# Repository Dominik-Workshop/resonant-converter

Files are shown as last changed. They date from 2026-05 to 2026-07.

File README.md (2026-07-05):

# Resonant Converter

 

<p align="center">
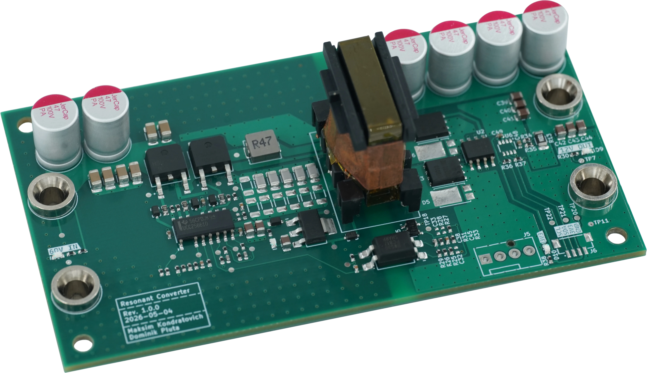
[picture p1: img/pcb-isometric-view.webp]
Hero image
  
</p>

## Overview

This project is an LLC resonant converter. The power supply is designed to step down a nominal 60V input to a 12V output, capable of delivering up to 10A of continuous current (120W).

The board features power telemetry using an INA219 sensor, which can be easily interfaced via a standard QWIIC connector.

### Key Features

* **Input Voltage:** 60V ± 5%
* **Output:** 12V @ 10A
* **Topology:** LLC Resonant Converter
* **Telemetry:** Onboard INA219 power monitor with a QWIIC I2C connector
* **Magnetics:** Custom-wound transformer

## Project Status

**Design:** ✅ → **Fabrication & Assembly:** ✅ → **Bring-up:** ✅

> [!IMPORTANT]
> **Hardware modification required (rev.1.0.0):**
>
> Replace `R20` with a diode (e.g. `1N4148`) to prevent VCCP from backfeeding `U3`. Without this fix, VCCP remains too low for the LLC controller `U1` to start up.

## Used Tools

* [KiCad](https://www.kicad.org/) - Schematic and PCB design

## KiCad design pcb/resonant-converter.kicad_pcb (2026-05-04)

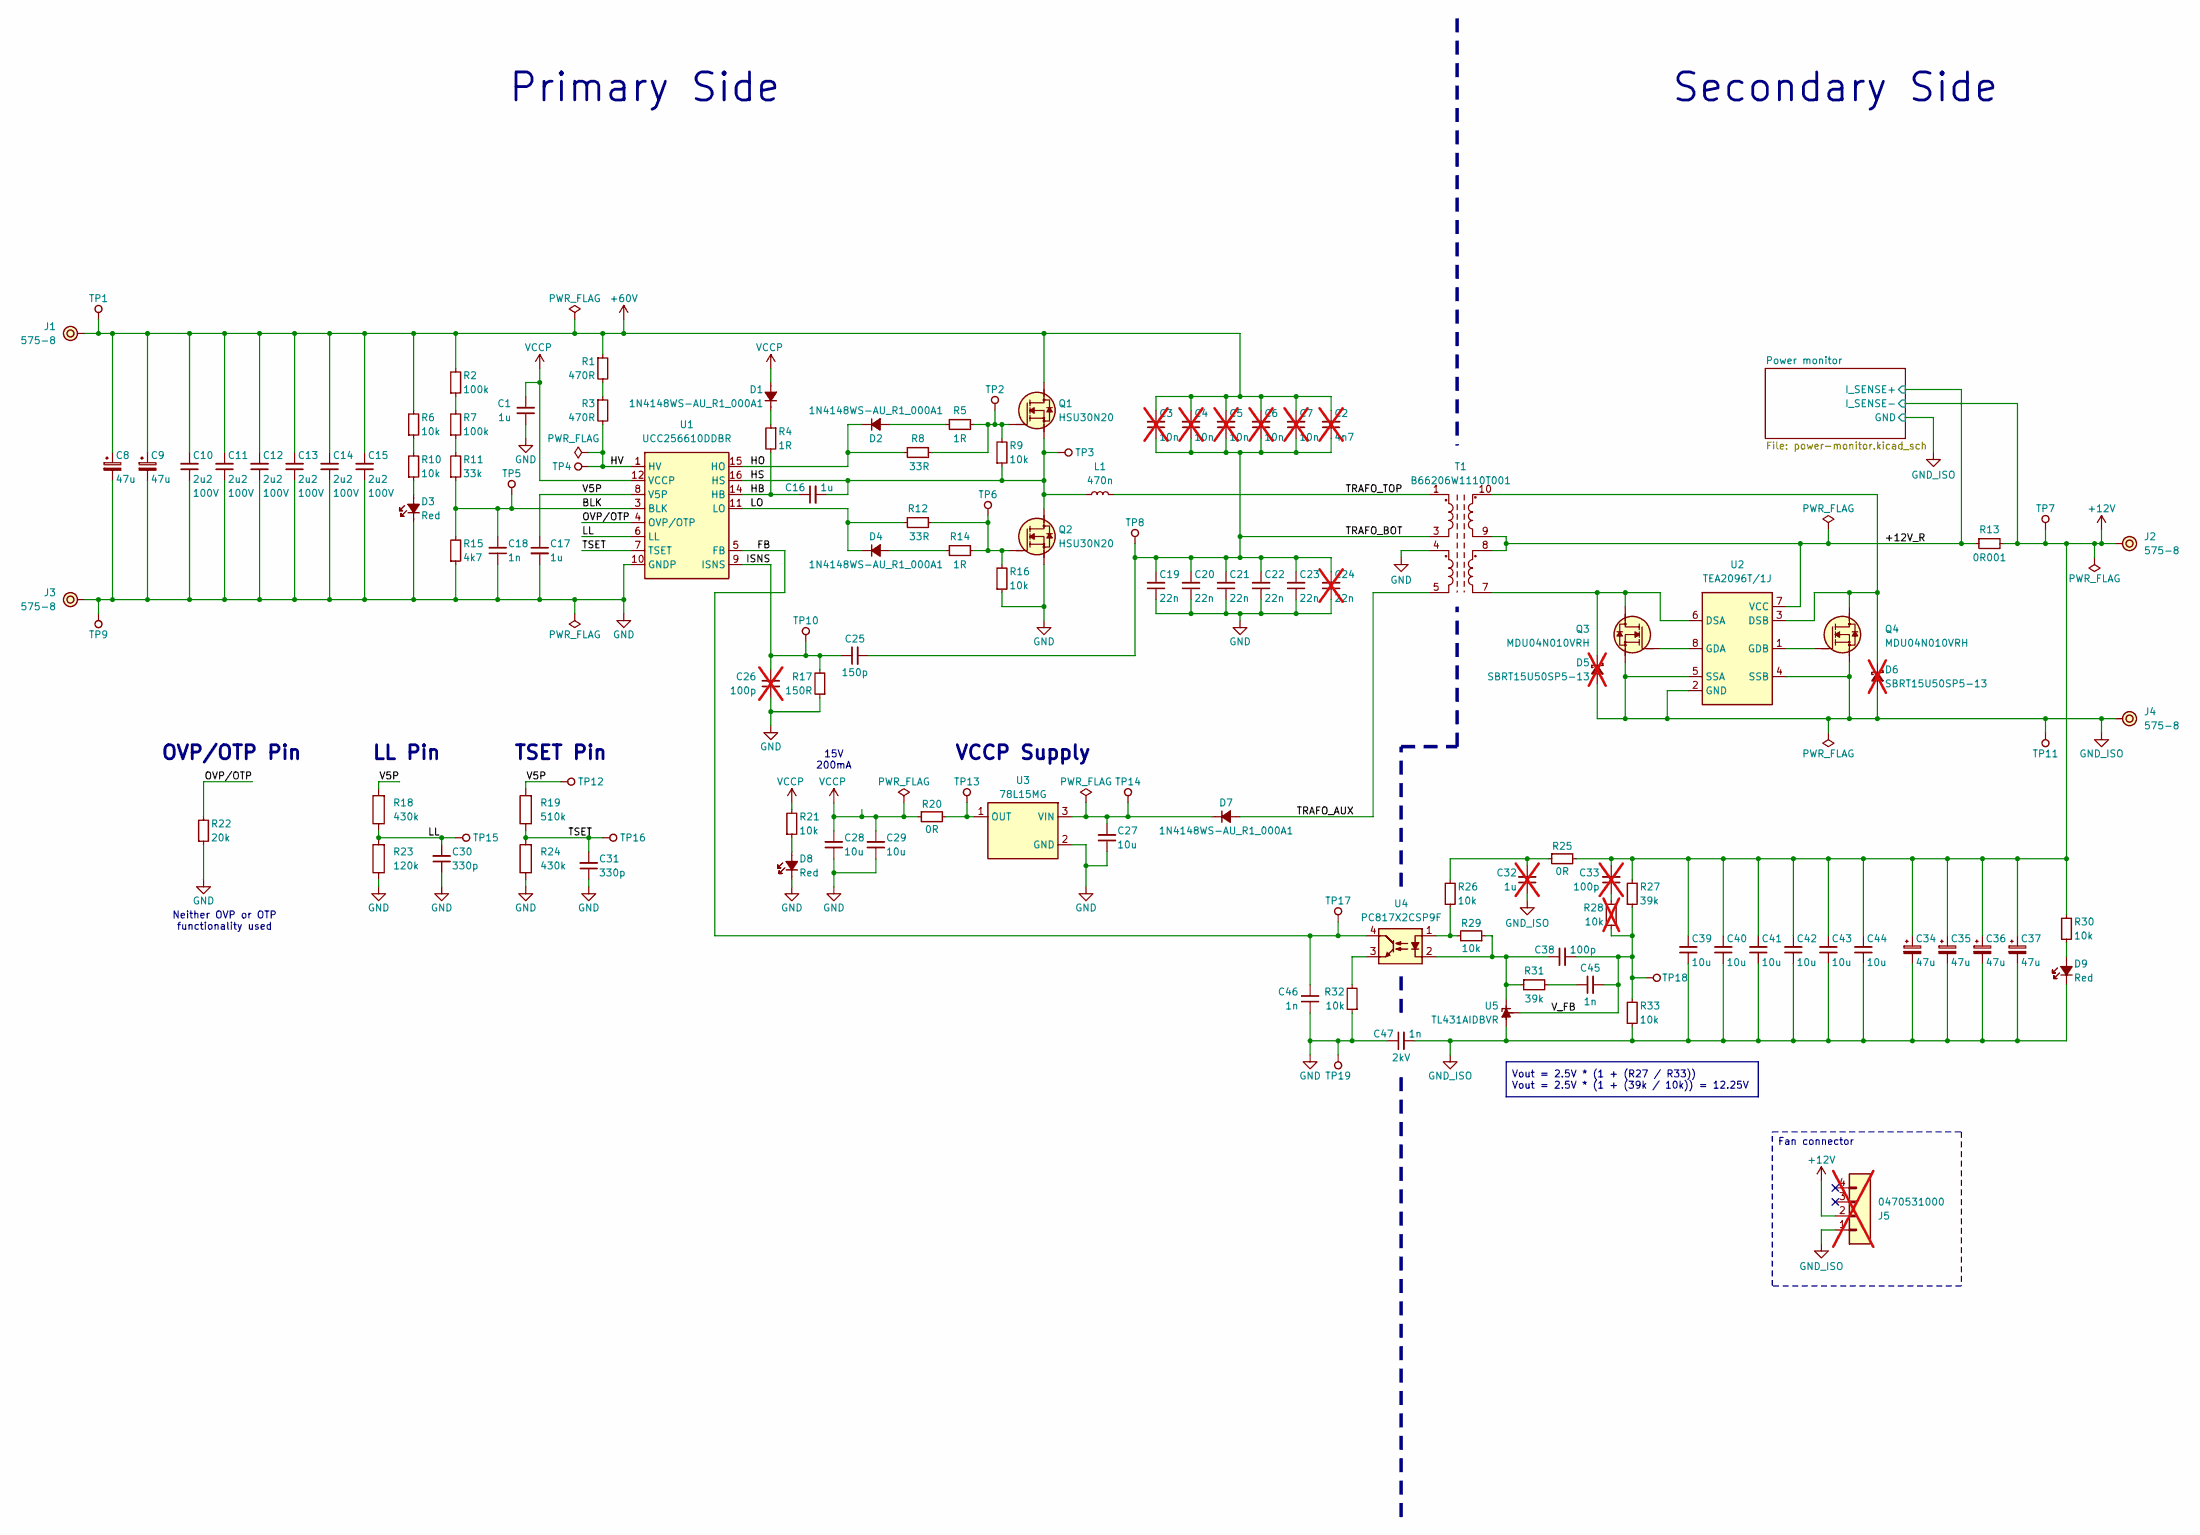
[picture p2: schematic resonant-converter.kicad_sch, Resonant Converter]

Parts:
C1, C16, C17: C-1u-0402; C_0402_1005Metric; Tolerance 10%; Voltage 25V; MPN CL05A105KA5NQNC; LCSC C52923
C2: C-4n7-100V-NP0-1206; C_1206_3216Metric; Tolerance 5%; Voltage 100V; MPN CC1206JRNPO0BN472; LCSC C577156; not fitted
C3, C4, C5, C6, C7: C-10n-100V-C0G-1206; C_1206_3216Metric; Tolerance 5%; Voltage 100V; MPN GCM3195C2A103JA16D; LCSC C184799; not fitted
C8, C9, C34, C35, C36, C37: C_Pol_47u_100V_D8mm_H11.5; C_Pol_D8mm_H11.5mm_P3.5mm; Tolerance 20%; Voltage 100V; MPN PA100V47M8X11; LCSC C49233039
C10, C11, C12, C13, C14, C15: C-2u2-100V-1206; C_1206_3216Metric; Tolerance 10%; Voltage 100V; MPN CL31B225KCHSNNE; LCSC C170101
C18, C45, C46: C-1n-0402; C_0402_1005Metric; Tolerance 10%; Voltage 50V; MPN 0402B102K500NT; LCSC C1523
C19, C20, C21, C22, C23: C-22n-100V-C0G-1206; C_1206_3216Metric; Tolerance 5%; Voltage 100V; MPN GRM3195C2A223JA01D; LCSC C711005
C24: C-22n-100V-C0G-1206; C_1206_3216Metric; Tolerance 5%; Voltage 100V; MPN GRM3195C2A223JA01D; LCSC C711005; not fitted
C25: C-150p-0402; C_0402_1005Metric; Tolerance 10%; Voltage 50V; MPN 0402B151K500NT; LCSC C1527
C26, C33: C-100p-0402; C_0402_1005Metric; Tolerance 5%; Voltage 50V; MPN 0402CG101J500NT; LCSC C1546; not fitted
C27, C28, C29, C39, C40, C41, C42, C43, C44: C-10u-0805; C_0805_2012Metric; Tolerance 10%; Voltage 50V; MPN GRM21BR61H106KE43L; LCSC C440198
C30, C31: C-330p-0402; C_0402_1005Metric; Tolerance 5%; Voltage 50V; MPN CL05C331JB5NNNC; LCSC C13533
C32: C-1u-0402; C_0402_1005Metric; Tolerance 10%; Voltage 25V; MPN CL05A105KA5NQNC; LCSC C52923; not fitted
C38: C-100p-0402; C_0402_1005Metric; Tolerance 5%; Voltage 50V; MPN 0402CG101J500NT; LCSC C1546
C47: C-1n-2kV-1206; C_1206_3216Metric; Tolerance 10%; Voltage 2kV; MPN 1206B102K202NT; LCSC C9196
D1, D2, D4, D7: 1N4148WS-AU; D_SOD-323F; Reverse Voltage 75V; MPN 1N4148WS-AU_R1_000A1; LCSC C2999083
D3, D8, D9: LED-R-0603_KT-0603R; LED_0603_1608Metric_R; Forward voltage 1.8V-2.4V; MPN KT-0603R; LCSC C2286
D5, D6: SBRT15U50SP5-13; PowerDI-5; Reverse Voltage 50V; MPN SBRT15U50SP5-13; LCSC C211388; not fitted
J1, J2, J3, J4: Banana_Jack_Keystone_575-8; Conn_Banana_Jack_Keystone_575-8; MPN 575-8; LCSC C4994335
J5: Molex_KK_1x4_0470531000; Conn_Molex_KK_1x4_0470531000; MPN 0470531000; LCSC C240840; not fitted
L1: L-470n-7A-dehongganying-DH0520H-R47M; L-dehongganying-DH0520H; Tolerance 20%; MPN DH0520H-R47M; LCSC C41407028
Q1, Q2: HSU30N20; TO-252-3; MPN HSU30N20; LCSC C42376812
Q3, Q4: MDU04N010VRH; PDFN-56-8; MPN MDU04N010VRH; LCSC C51891825
R1, R3: R-470R-0402; R_0402_1005Metric; Tolerance 1%; MPN 0402WGF4700TCE; LCSC C25117
R2, R7: R-100k-0402; R_0402_1005Metric; Tolerance 1%; MPN 0402WGF1003TCE; LCSC C25741
R4, R5, R14: R-1R-0603; R_0603_1608Metric; Tolerance Tolerance; MPN 0603WAF100KT5E; LCSC C22936
R6, R9, R10, R16, R21, R26, R29, R30, R32, R33: R-10k-0402; R_0402_1005Metric; Tolerance 1%; MPN 0402WGF1002TCE; LCSC C25744
R8, R12: R-33R-0402; R_0402_1005Metric; Tolerance 1%; MPN 0402WGF330JTCE; LCSC C25105
R11: R-33k-0402; R_0402_1005Metric; Tolerance 1%; MPN 0402WGF3302TCE; LCSC C25779
R13: R-0R001-1206; R_1206_3216Metric; Tolerance 5%; MPN FRM121WJR001TM; LCSC C7419993
R15: R-4k7-0402; R_0402_1005Metric; Tolerance 1%; MPN 0402WGF4701TCE; LCSC C25900
R17: R-150R-0402; R_0402_1005Metric; Tolerance 1%; MPN 0402WGF1500TCE; LCSC C25082
R18, R24: 430k; R_0402_1005Metric
R19: 510k; R_0402_1005Metric; LCSC C11616
R20, R25: R-0R-0402; R_0402_1005Metric; Tolerance 1%; MPN 0402WGF0000TCE; LCSC C17168
R22: R-20k-0402; R_0402_1005Metric; Tolerance 1%; MPN 0402WGF2002TCE; LCSC C25765
R23: 120k; R_0402_1005Metric; LCSC C25750
R27, R31: R-39k-0402; R_0402_1005Metric; Tolerance 1%; MPN 0402WGF3902TCE; LCSC C25783
R28: R-10k-0402; R_0402_1005Metric; Tolerance 1%; MPN 0402WGF1002TCE; LCSC C25744; not fitted
T1: B66206W1110T001; Bobbin_B66206W1110T001; MPN B66206W1110T001
TP1, TP2, TP3, TP4, TP5, TP6, TP7, TP8, TP9, TP10, TP11, TP12, TP13, TP14, TP15, TP16, TP17, TP18, TP19: TP_SMD_1mm
U1: UCC256610DDBR; DDB0014A; MPN UCC256610DDBR; LCSC C49247863
U2: TEA2096T/1J; SOIC-8_3.9x4.9mm_P1.27mm; MPN TEA2096T/1J; LCSC C5365715
U3: 78L15MG; SOT-223; MPN 78L15MG; LCSC C49451967
U4: PC817X2CSP9F; SMD-4_6.5x4.6mm_P2.54mm; MPN PC817X2CSP9F; LCSC C66405
U5: TL431AIDBVR; SOT-23-5; MPN TL431AIDBVR; LCSC C144392

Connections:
+12V: C33.2, C34.1, C35.1, C36.1, C37.1, C39.2, C40.2, C41.2, C42.2, C43.2, C44.2, J2.1, J5.2, R13.2, R25.2, R27.2, R30.2, TP7.1; also elsewhere on the board
+60V: C2.2, C3.2, C4.2, C5.2, C6.2, C7.2, C8.1, C9.1, C10.2, C11.2, C12.2, C13.2, C14.2, C15.2, J1.1, Q1.3 (D), R1.1, R2.2, R6.2, TP1.1
/+12V_R: R13.1, T1.8, T1.9, U2.7 (VCC); also elsewhere on the board
/BLK: C18.2, R11.1, R15.2, TP5.1, U1.3 (BLK)
/FB: C46.2, TP17.1, U1.5 (FB), U4.4
/HB: C16.1, R4.2, U1.14 (HB)
/HO: D2.1 (C), R8.1, U1.15 (HO)
/HS: C16.2, L1.1, Q1.2 (S), Q2.3 (D), R9.1, TP3.1, U1.16 (HS)
/HV: R3.2, TP4.1, U1.1 (HV)
/ISNS: C25.1, C26.2, R17.2, TP10.1, U1.9 (ISNS)
/LL: C30.2, R18.1, R23.2, TP15.1, U1.6 (LL)
/LO: D4.1 (C), R12.1, U1.11 (LO)
/OVP/OTP: R22.2, U1.4 (OVP/OTP)
/TRAFO_AUX: D7.2 (A), T1.5
/TRAFO_BOT: C2.1, C3.1, C4.1, C5.1, C6.1, C7.1, C19.2, C20.2, C21.2, C22.2, C23.2, C24.2, C25.2, T1.3, TP8.1
/TRAFO_TOP: L1.2, T1.1
/TSET: C31.2, R19.1, R24.2, TP16.1, U1.7 (TSET)
/V5P: C17.1, R18.2, R19.2, TP12.1, U1.8 (V5P)
/V_FB: C38.2, C45.2, R27.1, R28.1, R33.2, TP18.1, U5.4 (REF)
GND: C1.1, C8.2, C9.2, C10.1, C11.1, C12.1, C13.1, C14.1, C15.1, C17.2, C18.1, C19.1, C20.1, C21.1, C22.1, C23.1, C24.1, C26.1, C27.1, C28.1, C29.1, C30.1, C31.1, C46.1, C47.1, D3.1 (C), D8.1 (C), J3.1, Q2.2 (S), R15.1, R16.1, R17.1, R22.1, R23.1, R24.1, R32.1, T1.4, TP9.1, TP19.1, U1.10 (GNDP), U3.2 (GND), U3.4 (GND)
GND_ISO: C32.1, C34.2, C35.2, C36.2, C37.2, C39.1, C40.1, C41.1, C42.1, C43.1, C44.1, C47.2, D5.2 (A), D6.2 (A), D9.1 (C), J4.1, J5.1, Q3.1 (S), Q3.2 (S), Q3.3 (S), Q4.1 (S), Q4.2 (S), Q4.3 (S), R33.1, TP11.1, U2.2 (GND), U2.4 (SSB), U2.5 (SSA), U5.5 (A); also elsewhere on the board
unnamed: C32.2, R25.1, R26.2
unnamed: C33.1, R28.2
unnamed: C45.1, R31.2
unnamed: D1.1 (C), R4.1
unnamed: D2.2 (A), R5.1
unnamed: D3.2 (A), R10.1
unnamed: D4.2 (A), R14.1
unnamed: D5.1 (C), Q3.5 (D), T1.7, U2.6 (DSA)
unnamed: D6.1 (C), Q4.5 (D), T1.10, U2.3 (DSB)
unnamed: C27.2, D7.1 (C), TP14.1, U3.3 (VIN)
unnamed: D8.2 (A), R21.1
unnamed: D9.2 (A), R30.1
unnamed: Q1.1 (G), R5.2, R8.2, R9.2, TP2.1
unnamed: Q2.1 (G), R12.2, R14.2, R16.2, TP6.1
unnamed: Q3.4 (G), U2.8 (GDA)
unnamed: Q4.4 (G), U2.1 (GDB)
unnamed: R1.2, R3.1
unnamed: R2.1, R7.2
unnamed: R6.1, R10.2
unnamed: R7.1, R11.2
unnamed: R26.1, R29.2, U4.1
unnamed: R32.2, U4.3
unnamed: R20.2, TP13.1, U3.1 (OUT)
unnamed: C38.1, R29.1, R31.1, U4.2, U5.3 (K)
VCCP: C1.2, C28.2, C29.2, D1.2 (A), R20.1, R21.2, U1.12 (VCCP)

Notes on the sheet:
Secondary Side
VCCP Supply
TSET Pin
OVP/OTP Pin
LL Pin
Neither OVP or OTP functionality used
Primary Side
15V 200mA
Fan connector
Vout = 2.5V * (1 + (R27 / R33)) Vout = 2.5V * (1 + (39k / 10k)) = 12.25V

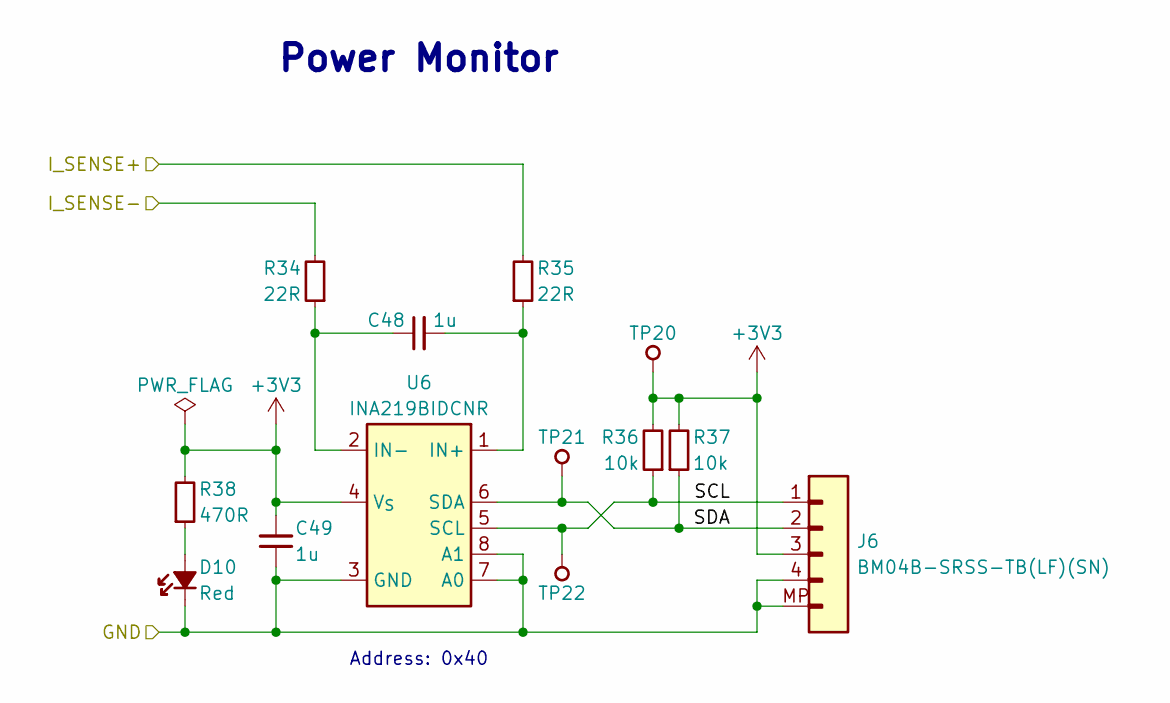
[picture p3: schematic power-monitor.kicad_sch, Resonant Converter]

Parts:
C48, C49: C-1u-0402; C_0402_1005Metric; Tolerance 10%; Voltage 25V; MPN CL05A105KA5NQNC; LCSC C52923
D10: LED-R-0603_KT-0603R; LED_0603_1608Metric_R; Forward voltage 1.8V-2.4V; MPN KT-0603R; LCSC C2286
J6: JST_SH_1x4_BM04B-SRSS-TB-LF-SN; Conn_JST_SH_1x4_BM04B-SRSS-TB; MPN BM04B-SRSS-TB(LF)(SN); LCSC C160390
R34, R35: R-22R-0402; R_0402_1005Metric; Tolerance 1%; MPN 0402WGF220JTCE; LCSC C25092
R36, R37: R-10k-0402; R_0402_1005Metric; Tolerance 1%; MPN 0402WGF1002TCE; LCSC C25744
R38: R-470R-0402; R_0402_1005Metric; Tolerance 1%; MPN 0402WGF4700TCE; LCSC C25117
TP20, TP21, TP22: TP_SMD_1mm
U6: INA219BIDCNR; SOT-23-8; MPN INA219BIDCNR; LCSC C962069

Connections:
+3V3: C49.2, J6.3, R36.2, R37.2, R38.2, TP20.1, U6.4 (V_{S})
+12V: R34.2; also elsewhere on the board
/+12V_R: R35.2; also elsewhere on the board
/Power monitor/SCL: J6.1, R36.1, TP22.1, U6.5 (SCL)
/Power monitor/SDA: J6.2, R37.1, TP21.1, U6.6 (SDA)
GND_ISO: C49.1, D10.1 (C), J6.4, J6.MP, U6.3 (GND), U6.7 (A0), U6.8 (A1); also elsewhere on the board
unnamed: D10.2 (A), R38.1
unnamed: C48.2, R35.1, U6.1 (IN+)
unnamed: C48.1, R34.1, U6.2 (IN-)

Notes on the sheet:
Address: 0x40
Power Monitor

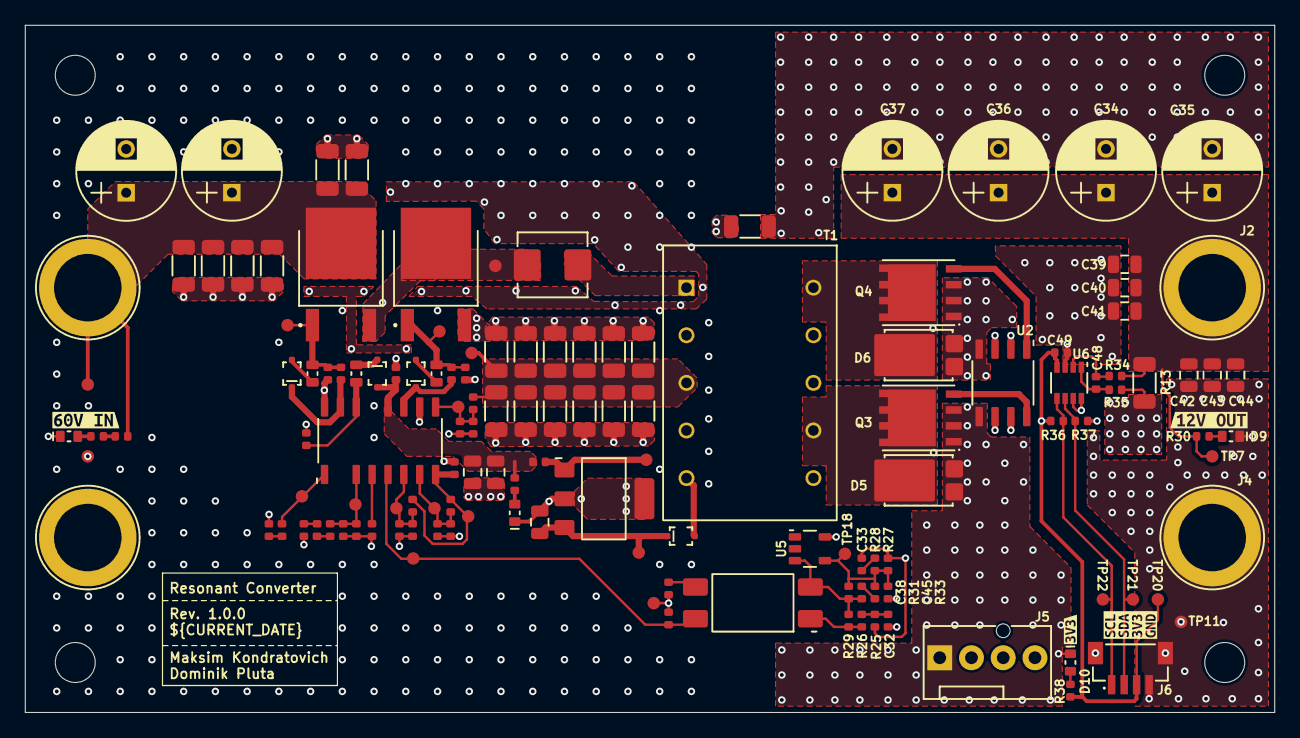
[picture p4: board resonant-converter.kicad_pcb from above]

Board: 4 copper layers, 100.0 x 55.0 mm, 141 parts (0 on the bottom side), 52 nets.

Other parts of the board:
kibuzzard-69F4E13D: G***; kibuzzard-69F4E13D
kibuzzard-69F4E155: G***; kibuzzard-69F4E155
kibuzzard-69F52FAE: G***; kibuzzard-69F52FAE
kibuzzard-69F53099: G***; kibuzzard-69F53099

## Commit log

2026-03-23 Initialize PCB project
    [resonant-converter.kicad_pcb, resonant-converter.kicad_sch]
2026-03-25 PCB: Setup PCB stackup, DRC and pre-defined sizes
    [resonant-converter.kicad_pcb]
2026-03-26 WIP: Create PCB mockup
    [resonant-converter.kicad_pcb, resonant-converter.kicad_sch]
2026-03-28 Add LLC controller IC
    [resonant-converter.kicad_pcb, resonant-converter.kicad_sch]
2026-03-28 Add output rectifier schottky diodes
    [resonant-converter.kicad_pcb, resonant-converter.kicad_sch]
2026-04-01 Add synchronous rectifier
    [resonant-converter.kicad_pcb, resonant-converter.kicad_sch]
2026-04-07 Add resonant inductor and capacitors
    [resonant-converter.kicad_pcb, resonant-converter.kicad_sch]
2026-04-12 [#4] Sch: Add INA219 power monitor
    [resonant-converter.kicad_sch]
2026-04-12 [#4] Sch: Add transformer, draft feedback circuitry
    [resonant-converter.kicad_sch]
2026-04-12 PCB: Update PCB from schematic, add transformer core
    [resonant-converter.kicad_pcb]
2026-04-13 [#4] Sch: Move INA219 power monitor to separate sheet, select initial feedback components values
    [power-monitor.kicad_sch, resonant-converter.kicad_sch]
2026-04-15 [#3] Add input capacitors and power indicator LED, change GND names on primary and secondary
    [power-monitor.kicad_sch, resonant-converter.kicad_sch]
2026-04-18 [#4] Sch: Add input and output capacitors, pri-sec interference capacitor and QWIIC connector, refactor schematic
    [power-monitor.kicad_sch, resonant-converter.kicad_sch]
2026-04-18 [#4] Sch: Change rectifier MOSFETS
    [resonant-converter.kicad_sch]
2026-04-18 [#3] Sch: Change primary side MOSFETS
    [resonant-converter.kicad_sch]
2026-04-20 [#4] Sch: Adjust feedback network component values, add optional compensation components
    [resonant-converter.kicad_sch]
2026-04-20 [#4] Sch: Add I2C pullups, write down INA219's address, add hierarchical label for power monitor's GND
    [power-monitor.kicad_sch, resonant-converter.kicad_sch]
2026-04-20 [#4] Sch: Add optional fan connector
    [resonant-converter.kicad_sch]
2026-04-20 [#4] Sch: Fill out title block in power monitor sheet
    [power-monitor.kicad_sch]
2026-04-22 [#3] Complete primary side schematic
    [resonant-converter.kicad_sch]
2026-04-22 Sch: Replace symbols with ones from library
    [resonant-converter.kicad_sch]
2026-04-22 Sch: Add 15V LDO for VCCP
    [resonant-converter.kicad_sch]
2026-04-22 Update PCB from schematic, add project info block on silkscreen
    [resonant-converter.kicad_pcb, resonant-converter.kicad_sch]
2026-04-22 WIP: Sch: Improve readability
    [resonant-converter.kicad_sch]
2026-04-22 Sch: Improve readability
    [resonant-converter.kicad_sch]
2026-04-22 Sch: Change output capacitors from 0603 to 0805
    [resonant-converter.kicad_sch]
2026-04-22 Sch: Decrease spacing between resonant capacitors
    [resonant-converter.kicad_sch]
2026-04-22 Re-annotate schematic, update PCB from schematic
    [power-monitor.kicad_sch, resonant-converter.kicad_pcb, resonant-converter.kicad_sch]
2026-04-22 Sch: Add test points and 3V3 power indicator LED
    [power-monitor.kicad_sch, resonant-converter.kicad_sch]
2026-04-22 Sch: Add 0R and 0402 1uF to VCCP line
    [resonant-converter.kicad_sch]
2026-04-22 Sch: Re-annotate schematic, clear ERC
    [power-monitor.kicad_sch, resonant-converter.kicad_sch]
2026-04-22 PCB: Update PCB from schematic, layout power monitor section
    [resonant-converter.kicad_pcb]
2026-04-22 PCB: Perform initial component placement
    [resonant-converter.kicad_pcb]
2026-04-22 README: Add badges and temporary PCB render
2026-04-25 Add mounting holes, fix 4n7 capacitor size
    [resonant-converter.kicad_pcb, resonant-converter.kicad_sch]
2026-05-01 Completed primary side PCB layout
    [power-monitor.kicad_sch, resonant-converter.kicad_pcb, resonant-converter.kicad_sch]
2026-05-01 WIP: Layout PCB secondary side
    [resonant-converter.kicad_pcb]
2026-05-01 PCB: Layout the rectifier
    [resonant-converter.kicad_pcb]
2026-05-02 PCB: Layout most of the secondary side
    [resonant-converter.kicad_pcb]
2026-05-02 PCB: Layout all secondary side connections
    [resonant-converter.kicad_pcb]
2026-05-02 PCB: Align PCB to bigger grid, arrange component designators, add via stitching on secondary side
    [resonant-converter.kicad_pcb]
2026-05-02 PCB: Clear DRC
    [resonant-converter.kicad_pcb]
2026-05-02 Update PCB render
2026-05-02 Added via stitching to the primary side
    [resonant-converter.kicad_pcb]
2026-05-04 Move PCB SHA, update date
    [power-monitor.kicad_sch, resonant-converter.kicad_pcb, resonant-converter.kicad_sch]
2026-07-04 Add PCB photo
